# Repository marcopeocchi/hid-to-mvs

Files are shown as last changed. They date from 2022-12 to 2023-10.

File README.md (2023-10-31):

# pico-hid-mvs

`pico-hid-mvs` is a budget-oriented adaptor between any supergun and a USB HID controller.  
It's based on the Rapsberry Pi pico and designed to be a plug and play solution.

It uses PIO for controlling the USB system and latency should be always in range of 1-2 ms.

Compiler: `arm-gcc-none-eabi`

## Setup
```
export TINYUSB_PATH=...
export PICO_SDK_PATH=...
```

## Build
```
mkdir build
cd build
cmake -DFAMILY=rp2040 ..
```

Under the `hw` directory there is all the necessary to produce and assembly the device.

<!---![Schematic_rp2040-ng_2023-10-30](https://github.com/marcopeocchi/hid-to-mvs/assets/35533749/b6dc0a2d-1c49-4163-ab82-408159b6241b)-->
pico-mvs

## Tested Controllers
- 8BitDo Ultimate C 2.4G
- 8Bitdo USB Arcade Stick (2.4G Mode)
- 8Bitdo NEOGEO Wireless Controller
- 8Bitdo M30 2.4G

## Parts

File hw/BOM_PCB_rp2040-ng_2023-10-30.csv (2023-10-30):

ID | Name | Designator | Footprint | Quantity | Manufacturer Part | Manufacturer | Supplier | Supplier Part | Price | Pins | 3DModel | JLCPCB Part Class
1 | 10nF | C2,C3,C1 | C0402 | 3 | CC0402KRX7R6BB103 | YAGEO(国巨) | LCSC | C541371 | 0.001 | 2 | C0402_L1.0-W0.5-H0.5 | Extended Part
2 | SN74AHCT125PWR | U2,U3,U1 | TSSOP-14_L5.0-W4.4-P0.65-LS6.4-BL | 3 | SN74AHCT125PWR | TI | LCSC | C36365 | 0.287 | 14 | TSSOP-14_L5.0-W4.4-H1.0-LS6.4-P0.65 | Extended Part
3 | TS-1088R-02026 | RESET | SW-SMD_L3.9-W3.0-P4.45 | 1 | TS-1088R-02026 | XUNPU | LCSC | C455280 | 0.047 | 2 | SW-SMD_L3.9-W2.9-H2.0-LS4.8 | Extended Part
4 | U-A-24DS-Y-1 | USB1 | USB-A-SMD_U-A-24DS-Y-1 | 1 | U-A-24DS-Y-1 | Rectangular Connectors - Contacts | LCSC | C193135 | 0.151 | 6 | USB-A-SMD_4P-L14.3-W10.0-H6.8 | Extended Part
5 | HDR, 1X20/2.54 | HDR1,HDR2 | HDR1X20/2.54_MALE | 2 |  |  | Mouser |  |  | 20
6 | DB15 | MVS1 | DSUB-TH_FDB1502-F0DB300K6KA | 1 | DB15 | null | LCSC | C9900014823 |  | 17 | DSUB-TH_FDB1502-F0DB300K6KA | Extended Part
7 | 150uF | C5 | C1206 | 1 | GRM31CR60J157ME11L | muRata(村田) | LCSC | C528968 | 0.8 | 2 | C1206_L3.2-W1.6-H1.3 | Extended Part
8 | 100nF | C6 | C0402 | 1 | 0402B104K160CT | Walsin(华新科) | LCSC | C83056 | 0.001 | 2 | C0402_L1.0-W0.5-H0.5 | Extended Part
9 | TPD3S014DBVR | U4 | SOT-23-6_L2.9-W1.6-P0.95-LS2.8-BR | 1 | TPD3S014DBVR | Texas Instruments | LCSC | C87384 | 0.929 | 6 | SOT-23-6_L2.9-W1.6-H1.5-LS2.8-P0.95 | Extended Part

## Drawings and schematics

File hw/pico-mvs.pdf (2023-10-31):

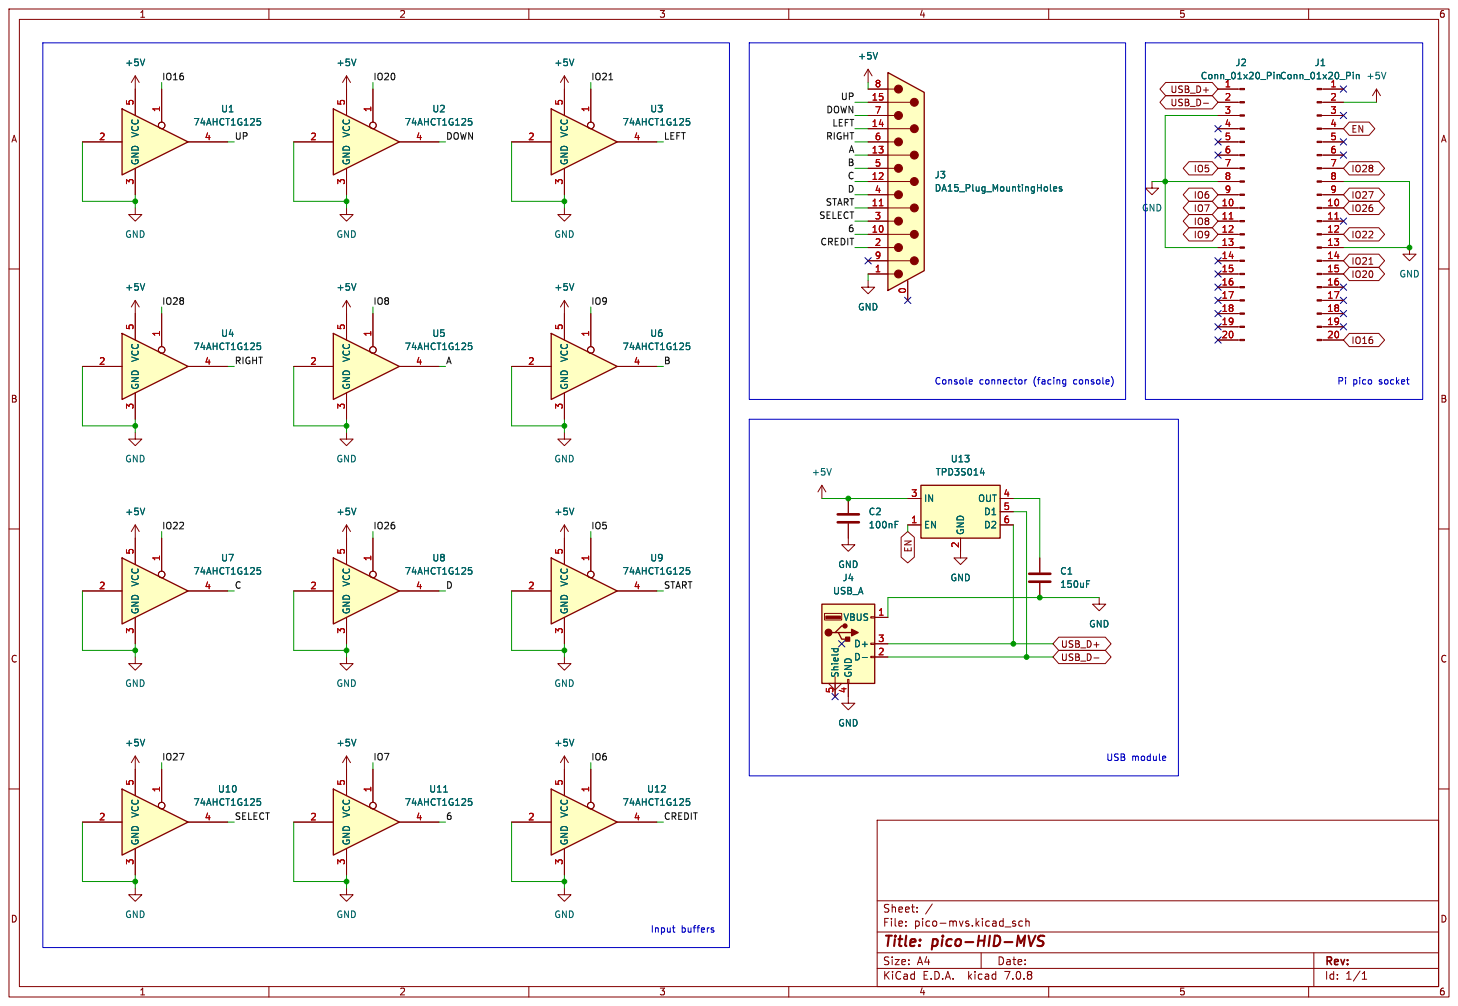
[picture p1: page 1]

Id: 1/1 Title: pico-HID-MVS

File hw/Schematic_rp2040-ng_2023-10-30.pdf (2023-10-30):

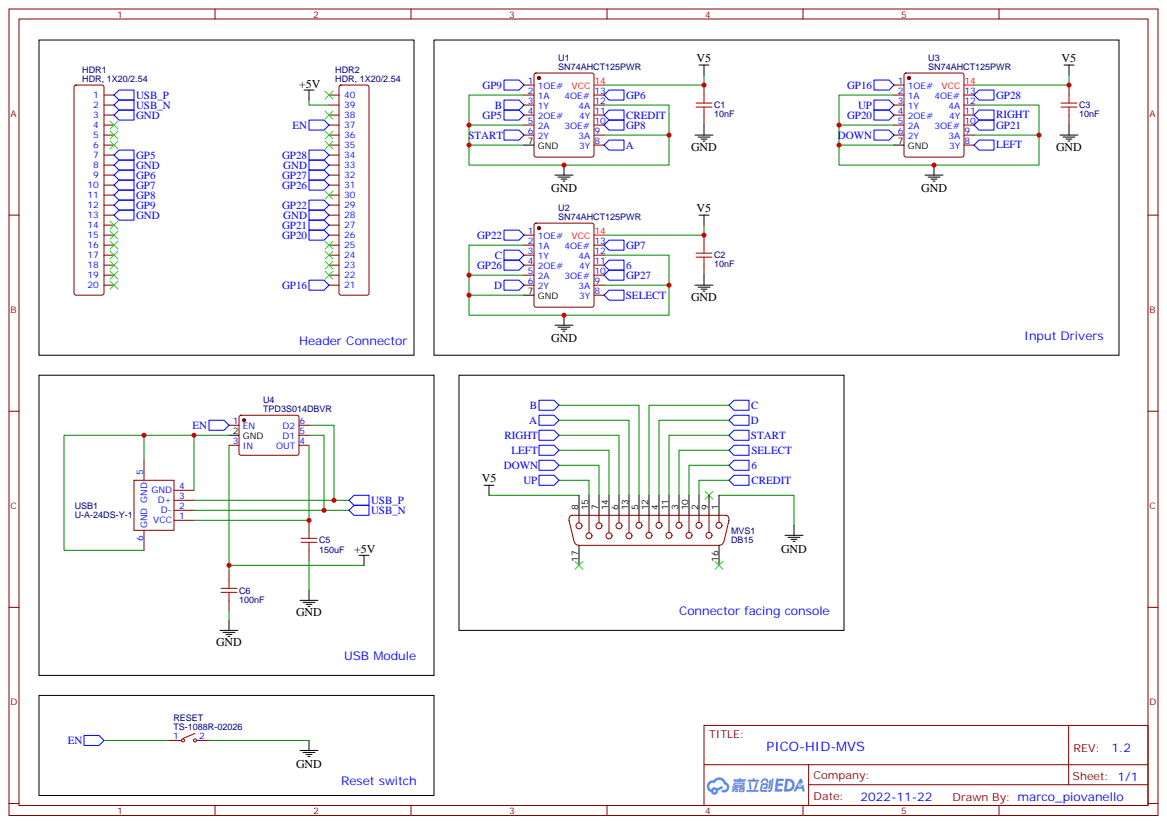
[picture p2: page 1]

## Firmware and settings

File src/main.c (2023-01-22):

#include <stdlib.h>
#include <stdio.h>
#include <string.h>

#include "bsp/board.h"
#include "tusb.h"

#include "board_layout.h"
#include "board_output.h"

void led_blinking_task(void);

extern void hid_app_task(void);

int main(void)
{
  board_init();
  board_output_init();

  tusb_init();

  while (1)
  {
    tuh_task();
    led_blinking_task();
    hid_app_task();
  }

  return 0;
}

// System-good task
// Blink every second to signal that the board has not crashed
void led_blinking_task(void)
{
  const uint32_t interval_ms = 1000;
  static uint32_t start_ms = 0;

  static bool led_state = false;

  if (board_millis() - start_ms < interval_ms)
    return;
  start_ms += interval_ms;

  board_led_write(led_state);
  led_state = 1 - led_state;
}

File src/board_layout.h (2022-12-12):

// ---------------------------------------------+
// MACRO GPIO pin number
// Using Raspberry Pi Pico board pin enumeration
// ---------------------------------------------+

#define A_PIN 8
#define B_PIN 9
#define X_PIN 22 // aka C button
#define Y_PIN 26 // aka D button

// directionals
#define DPAD_UP_PIN 16
#define DPAD_DOWN_PIN 20
#define DPAD_RIGHT_PIN 28
#define DPAD_LEFT_PIN 21

// utility
#define START_PIN 5
#define SELECT_PIN 27 // aka COIN trigger
#define ALT_6_PIN 7   // aka button 6 / mode 6

// shorthands for logic levels
#define HIGH 1
#define LOW 0

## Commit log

2022-05-31 updated doc
    [mvs-usb-2btn.fzz, mvs-usb-4btn.fzz]
2023-10-30 added bom, gerber, pap, schematics
    [BOM_PCB_rp2040-ng_2023-10-30.csv, PickAndPlace_PCB_rp2040-ng_2023-10-30.csv]
2023-10-31 Added schematics
